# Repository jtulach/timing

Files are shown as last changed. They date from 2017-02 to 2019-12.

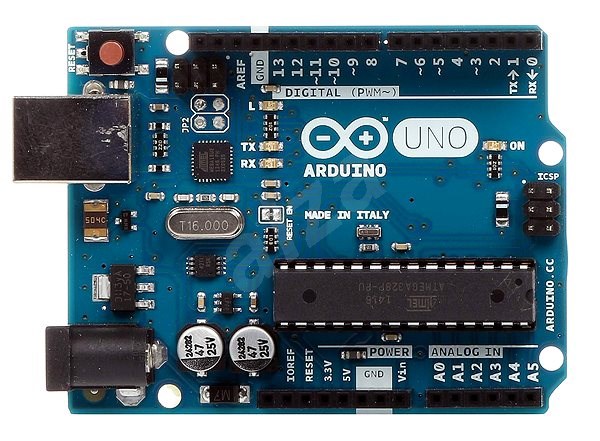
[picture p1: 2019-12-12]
boxes/aduino.jpg

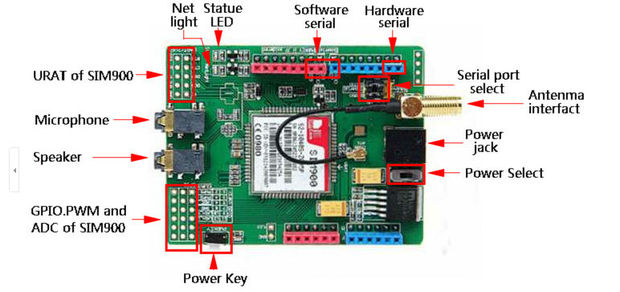
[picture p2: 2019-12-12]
boxes/FMSLB5AI84WXSAZ.MEDIUM.jpg

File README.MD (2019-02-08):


Build Status (http://hudson.apidesign.org/hudson/job/skimb/)

## Na startu

Po zapnutí krabičky, se rozsvítí červeně a svítí (nebliká) dokud se 
telefon neinicializuje. Jakmile telefon naváže spojení se sítí, začne 
ledka blikat sekundovým intervalem. Barva záleží na síle signálu, 
jakou telefon má. Signál může mít sílu 0 až 30. 

* bliká červeně -> síla signálu je menší než 10 a v takovém případě telefon defakto není schopen komunikovat
* bliká fialově -> síla signálu je mezi 10 a 14, telefon je schopen komunikovat, ale někdy se může stát, že nastane chyba
* bliká oranžově -> síla signálu je mezi 15 a 19, telefon by měl fungovat bez problému, ale odesílání zpráv na server může trvat delší dobu
* bliká zeleně -> síla signálu je větší než 19 a vše je super :)

Takže pokud začne blikat telefon sekundovým intervalem danou barvou, víme zhruba jak silný signál je. 

Když se projede startem, začne se odesílat zpráva na server. 
V tom případě začne svítít dioda modře (nebliká). Modře svítí po celou dobu komunikace se serverem. 
Délka závisi na kvalitě signálu a počtu chyb, které nastanou. 
Normálně by měla dioda svítít modře kolem jedná až třech sekund.  
Jakmile se zpráva odešle, tak začne dioda svítít červeně po dobu 15 sekund. 
Po tuto dobu se jen čeká, aby nebyly starty příliš za sebou. 
Po uplynutí 15 sekund, zase začne dioda blikat sekundovým intervalem barvou podle síly signálu. 

Kdyby náhodou svítíla dioda modře dlouhou dobu, tak komunikace 
se serverem se nějak zacyklila, zasekla,  a je nutné krabičku 
vypnout a zapnout znovu. 

## V cíli
 
Je to podobné jako na startu. Jen s tím rozdílem, že dioda ještě bliká 
červeně v intervalu 300ms, pokud není zaměřen laser správně. Takže 
po zapnutí krabičky svítí dioda červeně dokud se telefon neinicializuje a nepřihlásí se do sítě. 

Pak začne blikat rychle červeně (interval 300 milisekund)dokud není laser 
zaměřen správně. Laser by měl směřovat do prostřed čidla - čočky. 
Do  čidla by nemělo svítít přímé sluníčko, pak si čidlo totiž myslí, 
že tam svítí laser. Proto tam je teleskopické stínítko, které má také zabránit 
odleskům od sněhu. Za slunečního dne bude asi potřeba stínítko vysunout celé. 

Jakmile je laser zaměřen správně (čidlo snímá dostatečně silné světlo), 
tak začne dioda blikat sekundovým intervalem barvou podle síly signálu. 
Stejné barvy jako u startu. 

Pokud někdo projede cílem (přeruší laserový paprsek), tak se odešle zpráva na server. 
Během komunikace svítí dioda (nebliká) modře. Jakmile je zpráva odeslána, 
začne opět blikat podle síly signálu. V cíli není žádná pauza po odeslání 
jako na startu. Pokud dojde k přerušení laseru na delší dobu, začne opět blikat 
dioda červeně intervalem 300 ms a je nutné laser znovu zaměřit. 

Není to tak složité, jak to vypadá:).

Zdravím,
Petr

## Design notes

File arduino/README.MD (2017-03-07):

To get the sources to be compiled in the ArduinoIDE you have to create simlink in ${arduino_ide_install_path}/libraries to point the folder lib in this location.

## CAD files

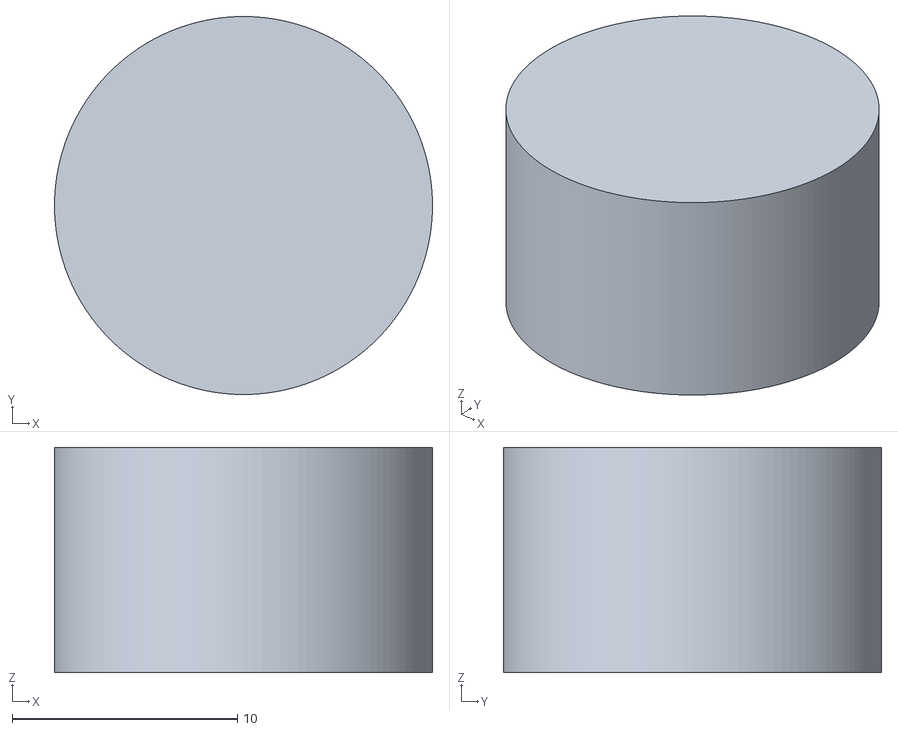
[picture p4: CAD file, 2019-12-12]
boxes/StartGage-LockPlankFull.stl
16.8 x 16.8 x 10.0

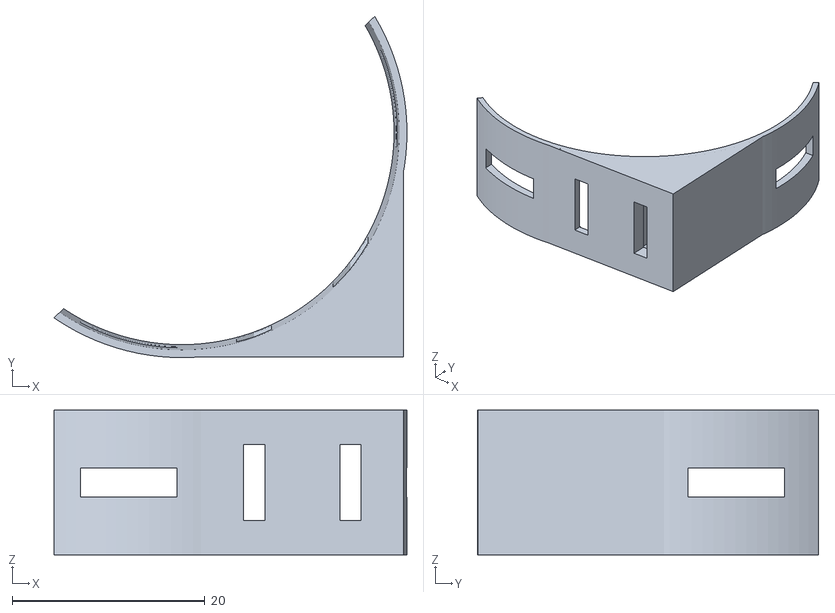
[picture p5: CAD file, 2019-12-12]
boxes/StartGage-MicroSwitchHolder.stl
36.6 x 35.4 x 15.0

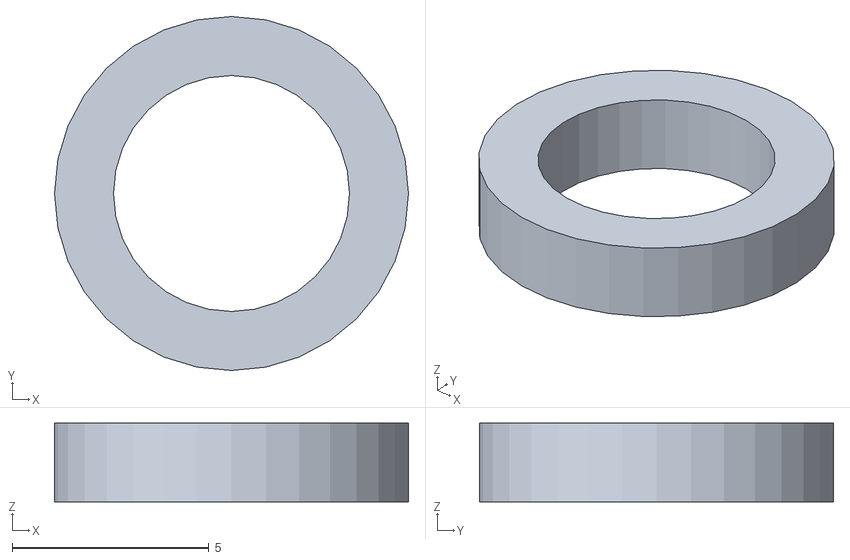
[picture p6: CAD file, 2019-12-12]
boxes/krabickaSFotoTransistorem_02-LaserPodlozka.stl
9.00 x 9.00 x 2.00

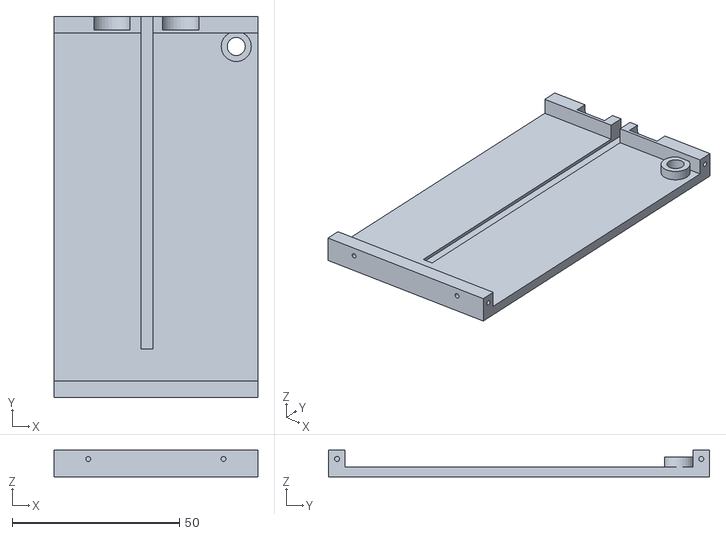
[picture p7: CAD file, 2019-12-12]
boxes/krabickaSFotoTransistorem_03-Left_Start1.stl
61.0 x 114.0 x 8.00

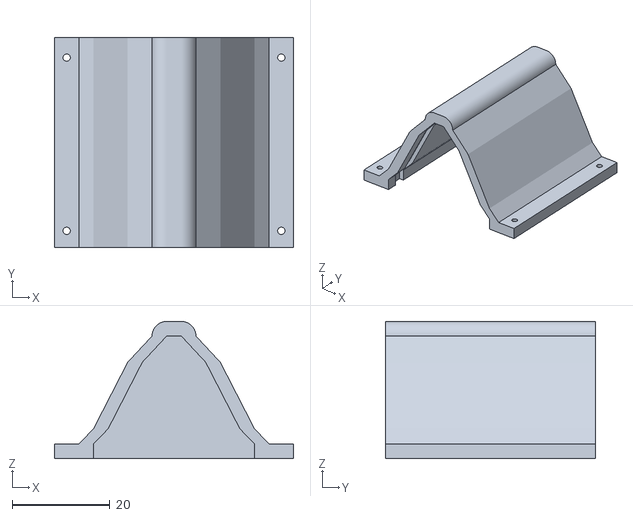
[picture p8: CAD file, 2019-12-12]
boxes/LaserBox-3LaserCaver.stl
49.0 x 43.1 x 28.1

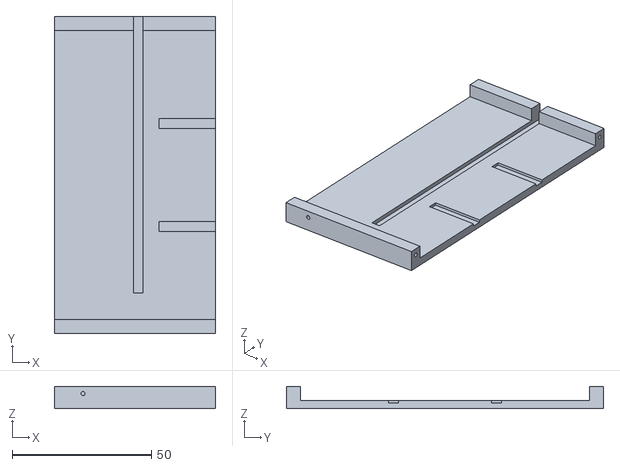
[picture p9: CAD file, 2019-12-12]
boxes/krabickaSFotoTransistorem_01-Right.stl
58.0 x 114.0 x 8.00

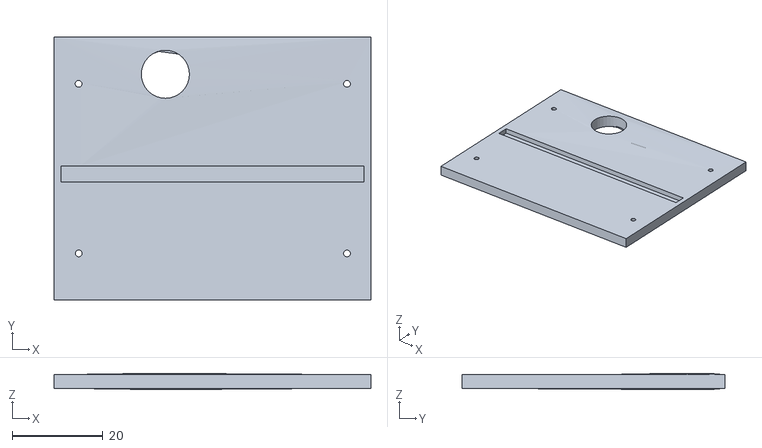
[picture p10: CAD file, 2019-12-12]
boxes/krabickaSFotoTransistorem_03-Beck.stl
70.0 x 58.0 x 3.54

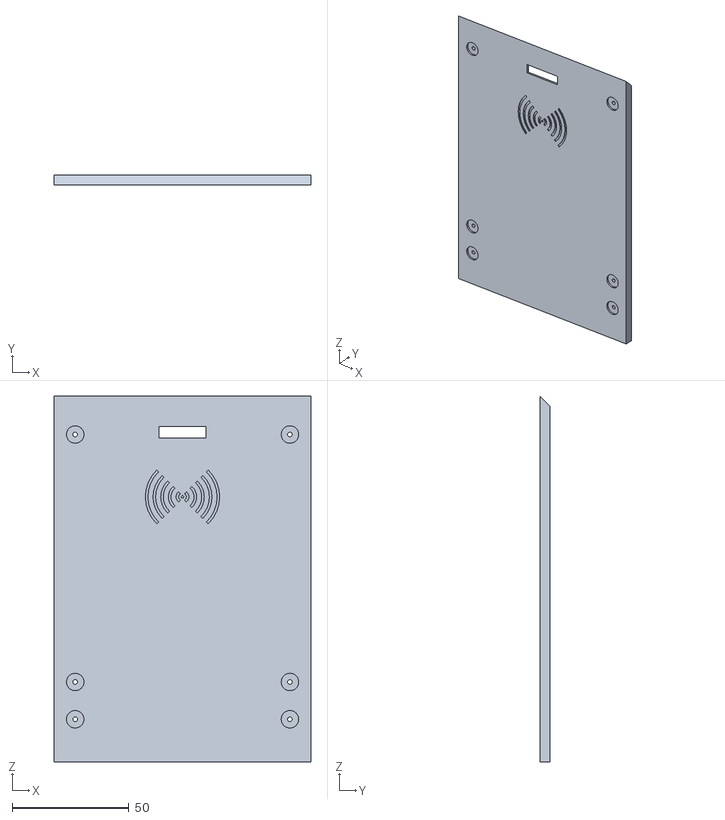
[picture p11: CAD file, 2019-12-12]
boxes/StartGage02-Box_Front.stl
110.0 x 4.34 x 156.8

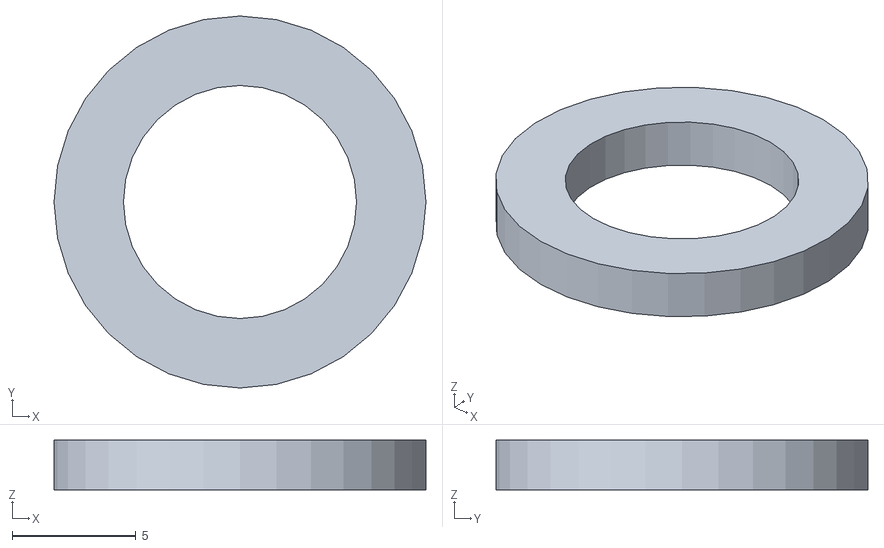
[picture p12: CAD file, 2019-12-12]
boxes/krabickaSFotoTransistorem_04-AntenaPad.stl
15.0 x 15.0 x 2.00

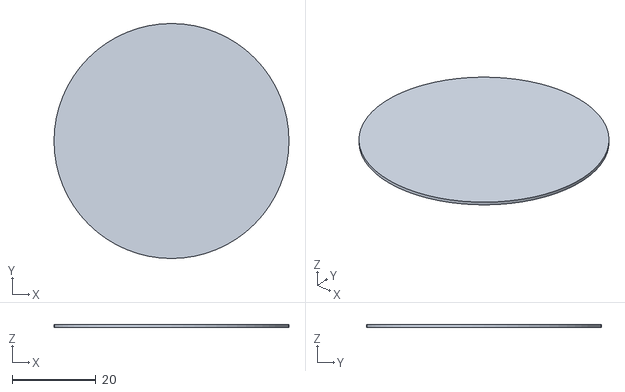
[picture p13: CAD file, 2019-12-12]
boxes/krabickaSFotoTransistorem_01-Glass0_7.stl
56.0 x 56.0 x 0.7

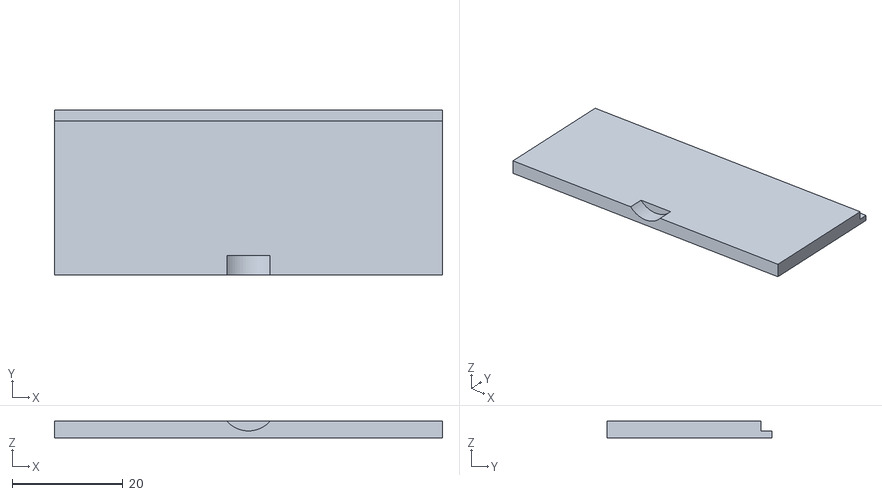
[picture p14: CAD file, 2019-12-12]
boxes/krabickaSFotoTransistorem_01-Front2.stl
70.0 x 29.8 x 3.00

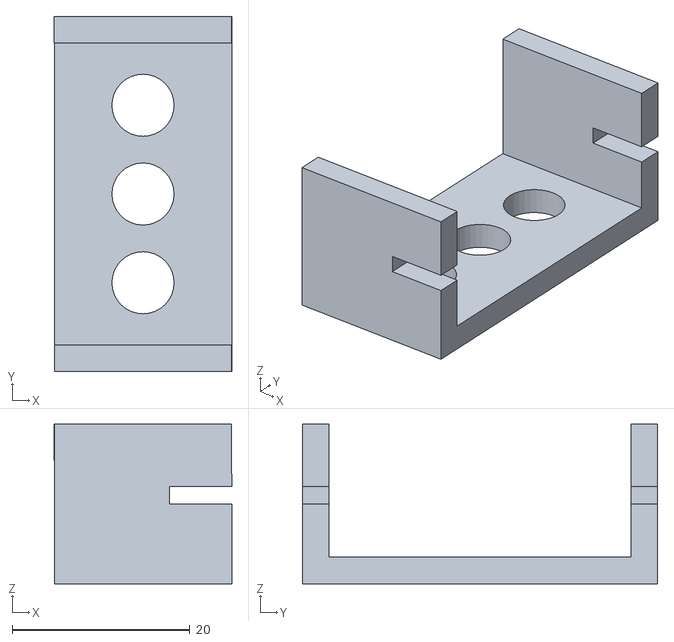
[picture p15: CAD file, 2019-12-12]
boxes/krabickaSFotoTransistorem_01-Handler.stl
20.0 x 40.0 x 18.0

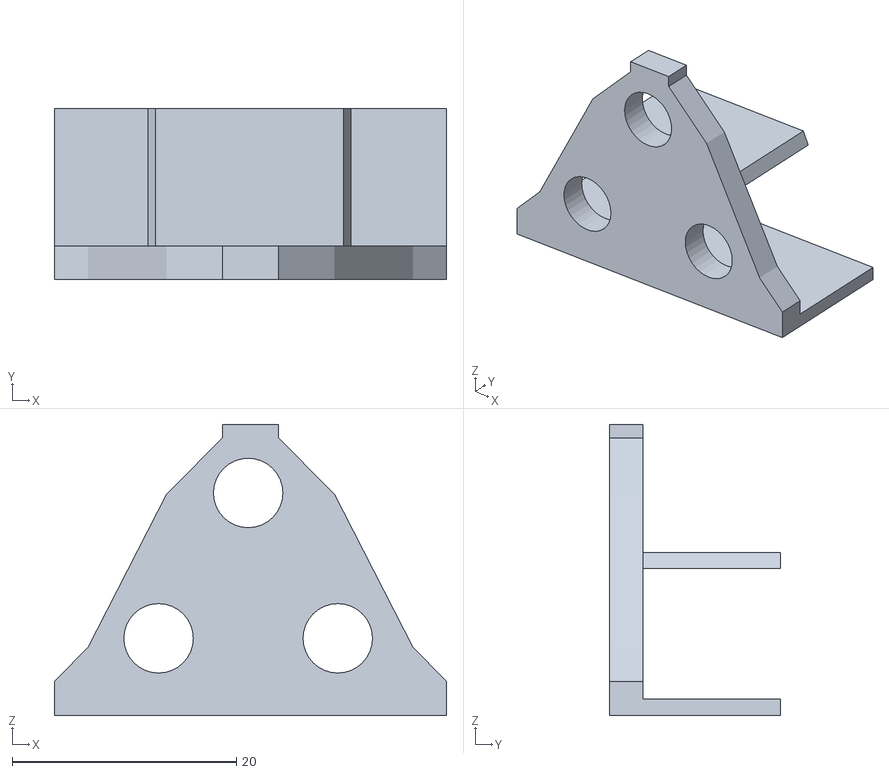
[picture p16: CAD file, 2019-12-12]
boxes/krabickaSFotoTransistorem_06-LaserBox-3LaserHolder.stl
35.0 x 15.3 x 26.0

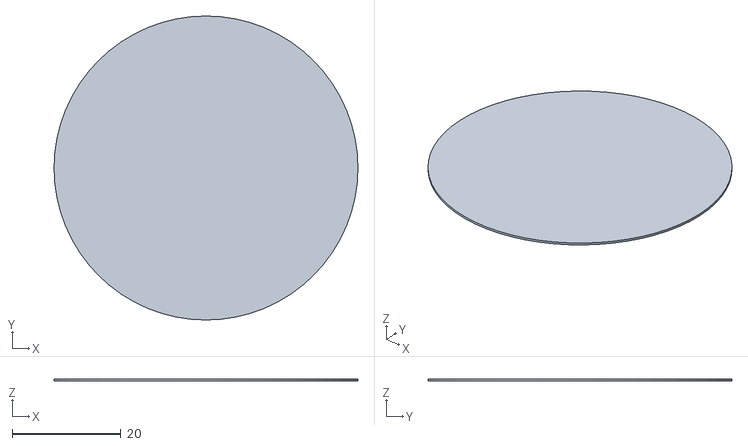
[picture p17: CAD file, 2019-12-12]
boxes/krabickaSFotoTransistorem_01-Glass0_4.stl
56.0 x 56.0 x 0.4

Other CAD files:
boxes/krabickaSFotoTransistorem_01-Left.stl
boxes/krabickaSFotoTransistorem_06-LaserBox-3LaserCaver.stl
boxes/StartGage02-Box_DsiplayCover_Part1.stl
boxes/krabickaSFotoTransistorem_04-Front1.stl
boxes/LaserBox-3LaserHolder.stl
boxes/LaserBox-3Leser-Top.stl
boxes/LaserBox-Back-Part1.stl
boxes/LaserBox-Back-Part2.stl
boxes/LaserBox-Bottom.stl
boxes/LaserBox-Front.stl
boxes/LaserBox-LaserBox-3LaserCaver.stl
boxes/LaserBox-Left.stl
boxes/LaserBox-Right.stl
boxes/LaserBox.blend
boxes/StartGage-LockCylinder.stl
boxes/StartGage-LockPlank.stl
boxes/StartGage-LockPlankWithHole.stl
boxes/StartGage-MicroSwitchHelper.stl
boxes/StartGage-MicroswitchHolder.stl
boxes/StartGage.blend
boxes/StartGage02-ArduinoBase.stl
boxes/StartGage02-Box_Back_Part1.stl
boxes/StartGage02-Box_Back_Part2.stl
boxes/StartGage02-Box_Bottom.stl
boxes/StartGage02-Box_DisplayCover_Part2.stl
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

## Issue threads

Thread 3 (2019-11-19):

The time in event can be wrong.

ppisl, 2019-11-19:
There is code in `startBox.cpp` and `finishBox.cpp`:
```
      unsigned long seconds = 10;
      unsigned long milliSeconds = 0;
      phone->getCurrentUnixTimeStamp(&seconds, &milliSeconds);
      int size = sprintf(cmd, "http://skimb.xelfi.cz/timing/add?when=%ld%d&type=START", seconds, milliSeconds);
```
The time can be wrong when `milliSeconds < 100`.

jtulach, 2019-11-19:
The following code prints the milliseconds correctly:
```
    long sec = 10;
    long millis = 9;
    char buffer[256];
    snprintf(buffer, 256, "time: %d%03d", sec, millis);
    printf("%s\n", buffer);
```

ppisl, 2019-11-20:
It has to be :
```
snprintf(buffer, 256, "time: %ld%03d", sec, millis);
```
Seconds are long.

jtulach, 2019-12-01:
Fine with me. Just provide the commit, please.

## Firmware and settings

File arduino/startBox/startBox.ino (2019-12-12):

#define DEBUG

#include <Phone.h>
#include <DebugUtils.h>
#include "LimitSwitch.h"

#define LIMIT_SWITCH_PIN 2
#define LIMIT_SWITCH_TIME_TO_SEND_START 300
#define BREAK_AFTER_SENDING 30   // time in seconds, when there is nothing check after sending start message. 


#define LED_RED_PIN A1  // this is analog pin now
#define LED_GREEN_PIN A2
#define LED_BLUE_PIN A3

#include <PN5180.h>
#include <PN5180ISO15693.h>

#define BUZZER_PIN 3

#include <LiquidCrystal_I2C.h>

// definování pinů pro PN5180
#define PN5180_NSS  10
#define PN5180_BUSY 6
#define PN5180_RST  5
PN5180ISO15693 nfc(PN5180_NSS, PN5180_BUSY, PN5180_RST);


LimitSwitch limitSwitch(LIMIT_SWITCH_PIN);

//unsigned long ledChange = 0;
unsigned long timeSignalCheck = 0;
#define TIME_SIGNAL_CHECK 10000




Phone *phone;
LiquidCrystal_I2C *lcd;
#define LCD_SAVE_TIMEOUT 60000 // switch lcd light off of
bool lcdLightOn = true;

char cmd[150];
unsigned long lastTimeMessageSend = 0; // when the last start message was send 
unsigned long lastActionTime = 0; // when the last action happend

// when time should be refreshed on display
byte lastSecond = 66;
byte lastMinute = 66;
byte lastHour = 25;

// remember the last readed id. It sended before the start.
char lastStartId[17];

void setup() {
  // init buzzer pin
  pinMode(BUZZER_PIN, OUTPUT);
  // init led pins
  pinMode(LED_RED_PIN, OUTPUT);
  pinMode(LED_GREEN_PIN, OUTPUT);
  pinMode(LED_BLUE_PIN, OUTPUT);
  
  playBootMelody();
  ledColor(1);
  
  Serial.begin(9600);
  // inicialization of LCD dislplay
  lcd = new LiquidCrystal_I2C(0x27,20,4);
  lcd->init();
  lcd->backlight();

  // init phone
  DEBUG_PRINTLN(F("Init phone..."));
  phone = new Phone(lcd);
  DEBUG_PRINTLN(F("calling Init phone..."));
  phone->init();
  lcd->clear();
  lcd->setCursor(0,0);
  lcd->print(F("Signal:00%"));
  lcd->setCursor(12,0);
  lcd->print(F("00:00:00"));
  ledColor(2);

  delay(2000);
  
  
  // for communication with FRID
  DEBUG_PRINTLN(F("Init nfc..."));
//  nfc = new PN5180ISO15693(PN5180_NSS, PN5180_BUSY, PN5180_RST);
  DEBUG_PRINTLN(F("nfc object vtytvoren"));
  nfc.begin();
  DEBUG_PRINTLN(F("nfc begin"));
  nfc.reset();
  DEBUG_PRINTLN(F("nfc reset"));

  DEBUG_PRINTLN(F("Enable RF field..."));
  nfc.setupRF();
  
  lastActionTime = millis();
  DEBUG_PRINTLN(F("Setup done!"));

  // sending message to the server about the start
  unsigned long seconds = 0;
  unsigned long milliSeconds = 0;
  phone->getCurrentUnixTimeStamp(&seconds, &milliSeconds);
  sprintf_P(cmd, PSTR("http://skimb.xelfi.cz/timing/add?when=%ld%03d&type=START_INITIALIZED"), seconds, milliSeconds);
  DEBUG_PRINTLN(cmd);
  phone->sendRequest(cmd);
}

void loop() {

  if ((millis() - timeSignalCheck) > TIME_SIGNAL_CHECK) { 
    timeSignalCheck = millis();
    checkSignalStrength();
  }


  if (lcdLightOn && (millis() - lastActionTime) > LCD_SAVE_TIMEOUT) {
    // save battery
    lcd->noBacklight();
    lcdLightOn = false;
  }
  
  displayTime();
  checkStart();
  checkCardReader();
}

void checkStart() {
  unsigned long switchTime = limitSwitch.isOn();

  if (switchTime > LIMIT_SWITCH_TIME_TO_SEND_START) {
    unsigned long current = millis();
    if ((current - switchTime) > lastTimeMessageSend) {
      DEBUG_PRINTLN(F("Sending start time"));
      unsigned long seconds = 0;
      unsigned long milliSeconds = 0;
      phone->getCurrentUnixTimeStamp(&seconds, &milliSeconds);
      ledColor(3);
      setLastActionTime();
      clearLcd();
      lcd->setCursor(0, 1);
      lcd->print(F("Odstartovano"));
      playStartMelody();
//      phone->createRequest(cmd, seconds, milliSeconds, F("START"));
      sprintf_P(cmd, PSTR("http://skimb.xelfi.cz/timing/add?when=%ld%03d&type=START"), seconds, milliSeconds);
      lastTimeMessageSend = current;
      DEBUG_PRINTLN(cmd);
      lcd->setCursor(0, 2);
      lcd->print(F("Posilani casu startu"));
      phone->sendRequest(cmd);
      lcd->setCursor(0, 2);
      lcd->print(F("Cas startu odeslan  "));
      lcd->setCursor(0, 3);
      lcd->print(F("Cekej    sekund"));
      ledColor(1);
      for (int i = BREAK_AFTER_SENDING; i >= 0; i--) {
        printTimePart(3, 6, i);
        delay(1000);
        displayTime();
        if (i ==  BREAK_AFTER_SENDING - 5) {
          clearLcd();
          lcd->setCursor(0, 3);
          lcd->print(F("Cekej    sekund"));
        }
        if(checkCardReader()) {
          clearLcd();
          lcd->setCursor(0, 3);
          lcd->print(F("Cekej    sekund"));
          i = i - 4;  // the action of card read takes about 4 seconds (melody, sending, timeout2s)
        }
      }
      printReady();
      timeSignalCheck = 0;
      ledColor(0);
    }
  }
  
}

// needed for reading PN5180
bool errorFlag = false;

bool checkCardReader() {
  if (errorFlag) {
    uint32_t irqStatus = nfc.getIRQStatus();
//    showIRQStatus(irqStatus);

//    if (0 == (RX_SOF_DET_IRQ_STAT & irqStatus)) { // no card detected
//      Serial.println(F("*** No card detected!"));
//    }

//    DEBUG_PRINTLN(F("*** No card detected!"));
    nfc.reset();
    nfc.setupRF();

    errorFlag = false;
  }

  uint8_t uid[8];
  ISO15693ErrorCode rc = nfc.getInventory(uid);
  if (ISO15693_EC_OK != rc) {
    //DEBUG_PRINT(F("Error in getInventory: "));
    //DEBUG_PRINTLN(nfc.strerror(rc));
    errorFlag = true;
    return false;
  }
  rc = nfc.getInventory(uid);
  if (ISO15693_EC_OK != rc) {
    errorFlag = true;
    return false;
  }
  rc = nfc.getInventory(uid);
  if (ISO15693_EC_OK != rc) {
    errorFlag = true;
    return false;
  }
  setLastActionTime();
  DEBUG_PRINT(F("Adresa RFID tagu: "));
  bytesToString(uid, 8, lastStartId);
  DEBUG_PRINTLN(lastStartId);
  
  clearLcd();
  lcd->setCursor(0, 1);
  lcd->print(F("Identifikovan cip"));
  lcd->setCursor(4, 2);
  lcd->print(lastStartId);
  playCardReadMelody();
  
  unsigned long seconds = 0;
  unsigned long milliSeconds = 0;
  ledColor(3);
  phone->getCurrentUnixTimeStamp(&seconds, &milliSeconds);
  
  unsigned long id = 0;
//  id += (unsigned long)uid[0] << 56;
//  id += (unsigned long)uid[1] << 48;
//  id += (unsigned long)uid[2] << 40;
//  id += (unsigned long)uid[3] << 32;
  id += (unsigned long)uid[4] << 24;
  id += (unsigned long)uid[5] << 16;
  id += (unsigned long)uid[6] << 8;
  id += (unsigned long)uid[7];
  DEBUG_PRINTLN(id);
//  phone->createRequest(cmd, seconds, milliSeconds, F("ASSIGN"));
//  sprintf_P(cmd, PSTR("%s&who=%s"), cmd, lastStartId);
  sprintf_P(cmd, PSTR("http://skimb.xelfi.cz/timing/add?who='%s'&when=%ld%03d&type=ASSIGN"), lastStartId, seconds, milliSeconds);
  DEBUG_PRINTLN(cmd);
  lcd->setCursor(0, 3);
  lcd->print(F("Posilani na server"));
  phone->sendRequest(cmd);
  delay(2000);
  timeSignalCheck = 0;
  ledColor(0);
  printReady();
  return true;
}

void checkSignalStrength() {
  DEBUG_PRINTLN(F("Checking signal started: "));
  int strength = phone->signalStrength();
  DEBUG_PRINTLN(F("Signal: "));
  DEBUG_PRINTLN(strength);
  
  if (strength >=0 && strength < 100) {
    // very easy way to conver it to % (30 should be max)
    int printValue = strength * 3;
    if (printValue >=0 && printValue < 100) {
      printTimePart(0, 7, printValue);
    }
  }
  if (strength < 10) {
    ledColor(1);
    clearLcd();
    lcd->setCursor(0,2);
    lcd->print(F("Slaby signal. Mozny"));
    lcd->setCursor(0,3);
    lcd->print(F("problem se spojenim."));
  } else {
    ledColor(2);
    printReady();
  }
}

void setLastActionTime() {
  lastActionTime = millis();
  if (!lcdLightOn) {
    lcd->backlight();
    lcdLightOn = true;
  }
}

void bytesToString(byte array[], unsigned int len, char buffer[]){
    for (unsigned int i = 0; i < len; i++) {  
        byte nib1 = (array[i] >> 4) & 0x0F;
        byte nib2 = (array[i] >> 0) & 0x0F;
        buffer[i*2+0] = nib1  < 0xA ? '0' + nib1  : 'A' + nib1  - 0xA;
        buffer[i*2+1] = nib2  < 0xA ? '0' + nib2  : 'A' + nib2  - 0xA;
    }
    buffer[len*2] = '\0';
}

void displayTime() {
  byte s = second();
  byte m = minute();
  byte h = hour();
  if (s != lastSecond) {
    printTimePart(0, 18, s);
    lastSecond = s;
    if (m != lastMinute) {
      printTimePart(0, 15, m);
      lastMinute = m;
      if (h != lastHour) {
        printTimePart(0, 12, h);
        lastHour = h;
      }
   }
  }
}

void printTimePart(byte row, byte column, byte number) {
  lcd->setCursor(column,row);
  if (number < 10) {
    lcd->print(0);
    lcd->print(number);
  } else {
    lcd->print(number);
  }
  
}

void printReady() {
  clearLcd();
  lcd->setCursor(0,3);
  lcd->print(F("Muzes startovat"));  
}

void clearLcd(){
  lcd->setCursor(0,1);
  lcd->print(F("                    "));
  lcd->setCursor(0,2);
  lcd->print(F("                    "));
  lcd->setCursor(0,3);
  lcd->print(F("                    "));  
}

void playBootMelody() {
  tone(BUZZER_PIN, 200, 250);
  delay(300);
  tone(BUZZER_PIN, 400, 250);
  delay(300);
  tone(BUZZER_PIN, 600, 250);
  delay(300);
}

void playCardReadMelody() {
  tone(BUZZER_PIN, 300, 400);
  delay(450);
  tone(BUZZER_PIN, 600, 800);
  delay(800);
}

void playStartMelody() {
  tone(BUZZER_PIN, 200, 100);
  delay(150);
  tone(BUZZER_PIN, 200, 100);
  delay(150);
  tone(BUZZER_PIN, 200, 100);
  delay(150);
  tone(BUZZER_PIN, 200, 100);
  delay(150);
  tone(BUZZER_PIN, 100, 2000);
  delay(800);
}

void ledColor(byte color) {
  if (color == 1) {
    digitalWrite (LED_RED_PIN, HIGH);
    digitalWrite (LED_BLUE_PIN, LOW);
    digitalWrite (LED_GREEN_PIN, LOW);
  } else if (color == 3) {
    digitalWrite (LED_RED_PIN, LOW);
    digitalWrite (LED_BLUE_PIN, HIGH);
    digitalWrite (LED_GREEN_PIN, LOW);
  } else if (color == 2) {
    digitalWrite (LED_RED_PIN, LOW);
    digitalWrite (LED_BLUE_PIN, LOW);
    digitalWrite (LED_GREEN_PIN, HIGH);
  } else {
    digitalWrite (LED_RED_PIN, LOW);
    digitalWrite (LED_BLUE_PIN, LOW);
    digitalWrite (LED_GREEN_PIN, LOW);
  }
}

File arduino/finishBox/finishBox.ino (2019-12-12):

#define DEBUG

#include <RGBLed.h>
#include <Phone.h>
#include <DebugUtils.h>

#define PIN_LDR         A0 // where is the value from photo resistor readed

#define LED_RED_PIN     6
#define LED_GREEN_PIN   10
#define LED_BLUE_PIN    3

RGBLed led(LED_RED_PIN, LED_GREEN_PIN, LED_BLUE_PIN);


unsigned long ledChange = 0;
unsigned long timeSignalCheck = 0;
#define TIME_SIGNAL_CHECK 10000

int workingResistorValue = 600;
int minimalMessageDelay = 2; // number of seconds, when the message can not be sand again

Phone *phone;

char cmd[150];
unsigned long lastTimeMessageSend = 0; // when the last start message was send
unsigned long laserDetectedTime = 0;
unsigned long lastMessageTime = 0;
unsigned long timeToChangeLed = 300;


void setup() {
  Serial.begin(9600);
  led.setColor(250, 40, 0);
  led.on();
  phone = new Phone(NULL);
  phone->init();
  // sending message about starting box
  DEBUG_PRINTLN(F("Sending FINISH_INITIALIZED"));
  unsigned long seconds = 0;
  unsigned long milliSeconds = 0;
  phone->getCurrentUnixTimeStamp(&seconds, &milliSeconds);
//  phone->createRequest(cmd, &seconds, &milliSeconds, F("FINISH_INITIALIZED"));
  sprintf(cmd, "http://skimb.xelfi.cz/timing/add?when=%ld%03d&type=FINISH_INITIALIZED", seconds, milliSeconds);
  phone->sendRequest(cmd);
}

void loop() {
  unsigned long current = millis();
  int resistorValue = getResistorValue();
  if ((current - timeSignalCheck) > TIME_SIGNAL_CHECK) {
    timeSignalCheck = current;
    checkSignalStrength();
    DEBUG_PRINT("LDR value is ");
    DEBUG_PRINTLN(resistorValue);
  }
  if (resistorValue > workingResistorValue) {
    laserDetectedTime = current;
    timeToChangeLed = 1000;
  } else {
    if ((current - laserDetectedTime) >  10000) {     // laser was not detected for 10 seconds
      //DEBUG_PRINT("Laser is not detected longer then 10s, LDR value is: ");
      // DEBUG_PRINTLN(resistorValue);
      led.setColor(250, 0, 0);
      timeToChangeLed = 300;
      delay(100);
    } else {
      unsigned long messageDelay = current - lastMessageTime;
      if (messageDelay > 2000  && messageDelay > (minimalMessageDelay * 1000)
          && (laserDetectedTime > lastMessageTime)) {
        unsigned long seconds = 0;
        unsigned long milliSeconds = 0;
        current = millis();
        DEBUG_PRINTLN(F("Sending finish time"));
        phone->getCurrentUnixTimeStamp(&seconds, &milliSeconds);
//        int size = phone->createRequest(cmd, seconds, milliSeconds, F("FINISH"));
        int size = sprintf(cmd, "http://skimb.xelfi.cz/timing/add?when=%ld%03d&type=FINISH", seconds, milliSeconds);
        lastMessageTime = current;
        led.setColor(0, 0, 250);
        led.on();
        phone->sendRequest(cmd);
        timeSignalCheck = 0;
        lastMessageTime = current;
      }
    }
  }

  if ((millis() - ledChange) > timeToChangeLed) {
    ledChange = millis();
    if (led.isOn()) {
      led.off();
    } else {
      led.on();
    }
  }
}

boolean isLaserDetected() {
  int resistorValue = getResistorValue();
  if (resistorValue < workingResistorValue) {
    unsigned long current = millis();
    if ((current - ledChange) > 1000) {
      led.setColor(255, 0, 0);
      return false;
    }
  }
  return true;
}

int getResistorValue() {
  return analogRead(PIN_LDR);
}

void checkSignalStrength() {
  int strength = phone->signalStrength();
  if (strength < 10) {
    led.setColor(255, 0, 0);  // red
  } else if (strength > 9 && strength < 15) {
    led.setColor(250, 0, 100); // magnata
  } else if (strength > 14 && strength < 20) {
    led.setColor(250, 40, 0); // orange
  } else if (strength > 19 ) {
    led.setColor(0, 250, 0);
  }
}

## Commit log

2017-03-07 Always print two digits for minutes and seconds
2017-03-12 When new START event arrives, take the current person on start
2017-03-16 Next and prev record buttons
2017-03-18 Only START records shall have next and prev buttons enabled
2018-02-26 Adding code for finish box and stl files and blender files for printing boxes.
    [krabickaSFotoTransistorem_01-Beck.stl, krabickaSFotoTransistorem_01-Bottom.stl, krabickaSFotoTransistorem_01-DeskaProstredni_001.stl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]
2019-01-11 Computing the record time based on Current
2019-01-12 Don't connect ignored timers on finish
2019-01-14 Can continue the latest timer
2019-02-03 Keep reference to currentConnection
2019-02-08 Can switch between different measurements
2019-02-10 Call it "zrušit" button
2019-02-10 Switch the list of measurements
2019-02-13 Refresh is the most important button
2019-03-08 Minus button to unalias extra connected ID for a contact
2019-11-10 Switching to HTML/Java API version 1.7 which contains two new desktop presenters
2019-11-19 Saving memory
    [krabickaSFotoTransistorem_05.blend]
2019-11-20 Final code of saving memory in start box. Fix for: Issue #1- The time in event can be wrong.
    [finishBox.ino, startBox.ino]
2019-11-20 Updating boxes
    [LaserBox-3LaserCaver.stl, LaserBox-3LaserHolder.stl, LaserBox-3Leser-Top.stl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]
